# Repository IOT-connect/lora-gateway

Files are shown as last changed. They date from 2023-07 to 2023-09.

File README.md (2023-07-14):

# Lora gateway with ethernet

## Project for make simple and reliable Lora gateway with AVR atmega2560 and ESR-US1 w5500 ethernet

#### 3d view

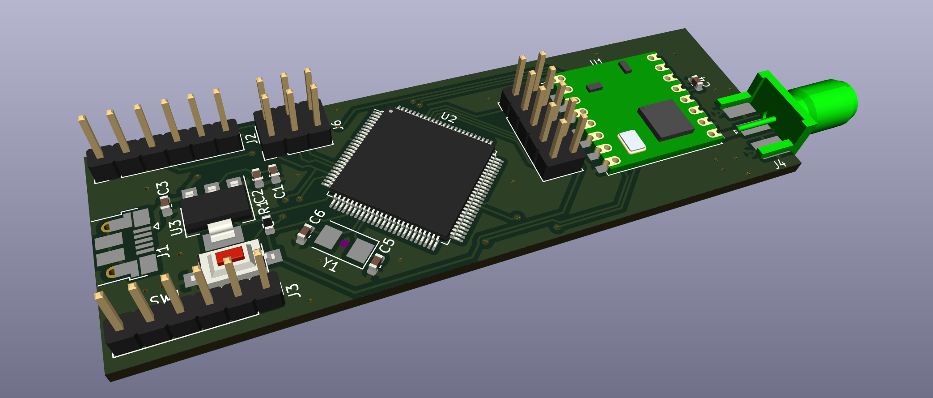
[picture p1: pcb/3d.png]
3d


#### pcb view

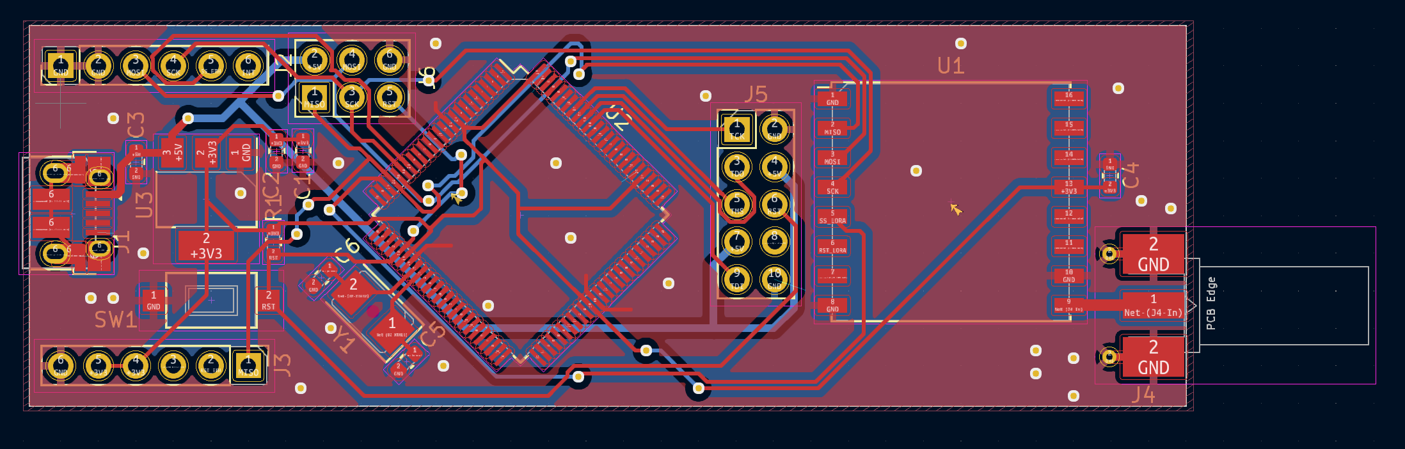
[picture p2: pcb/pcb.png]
pcb


#### schematic view

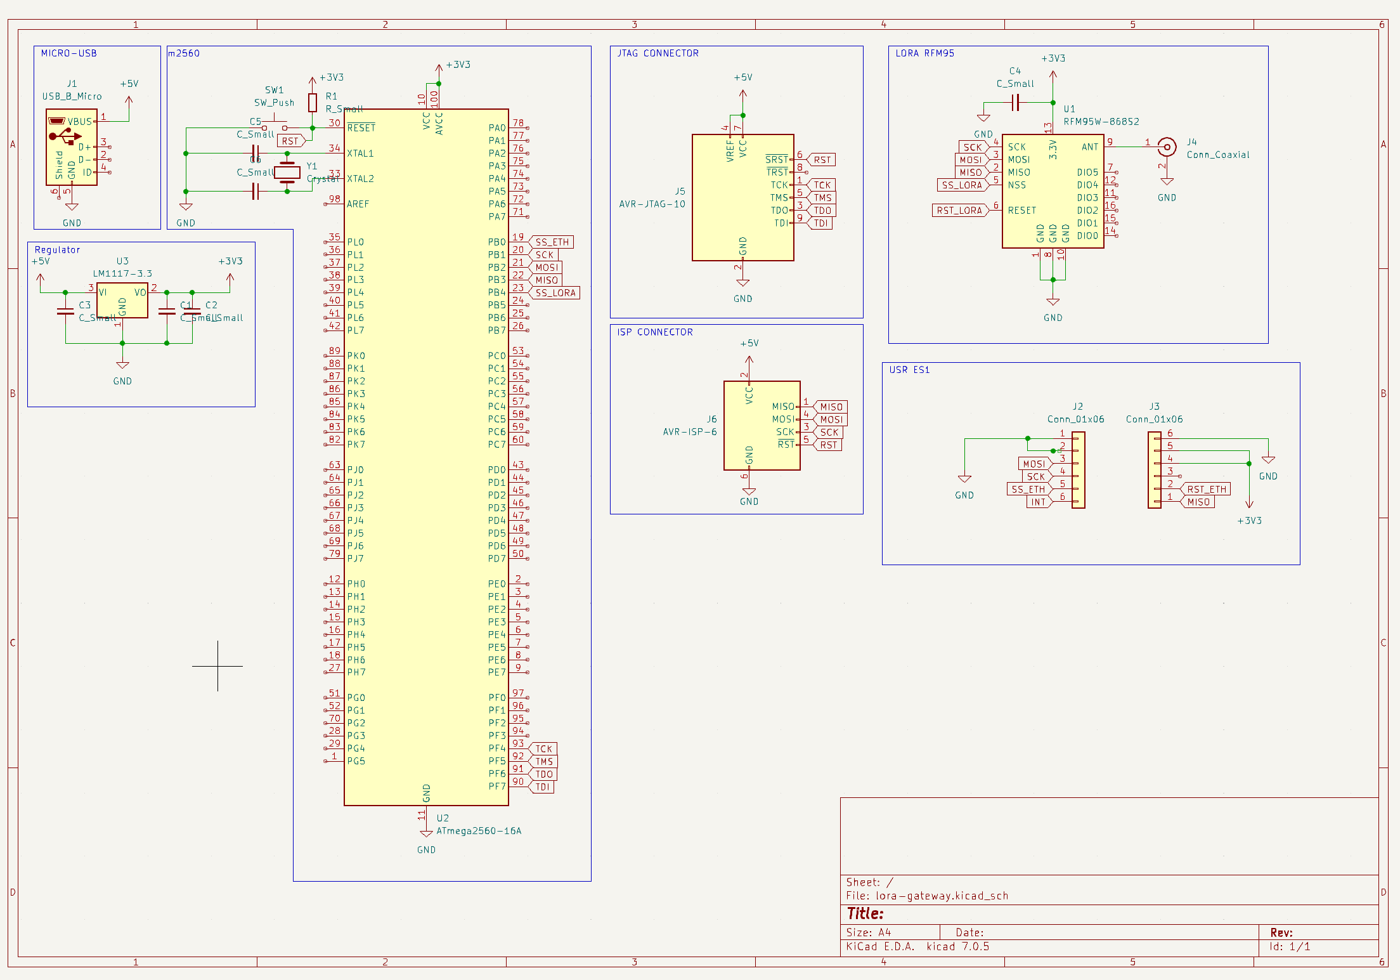
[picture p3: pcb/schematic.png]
schematic


### TODO

- [ ] Add RTC
- [ ] Add temperature sensor

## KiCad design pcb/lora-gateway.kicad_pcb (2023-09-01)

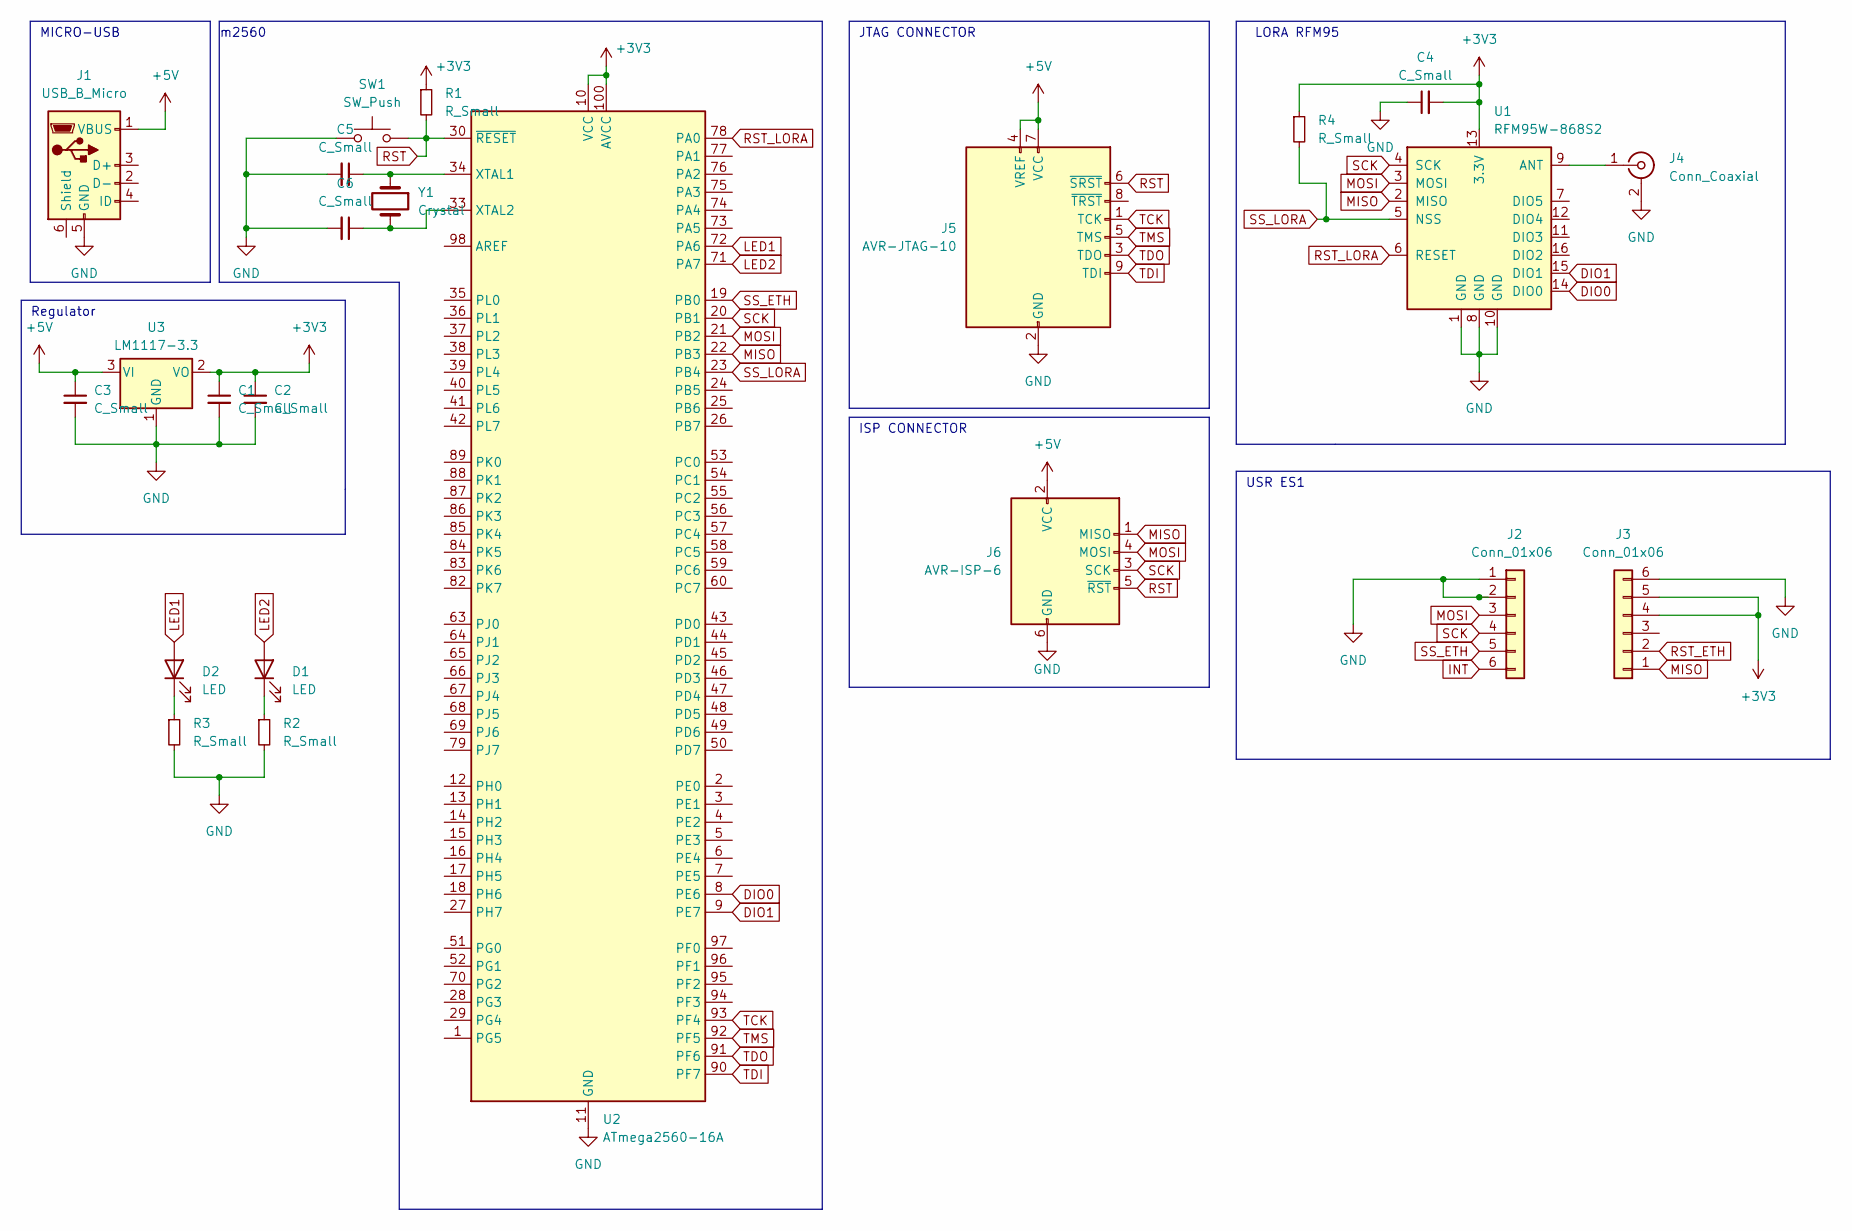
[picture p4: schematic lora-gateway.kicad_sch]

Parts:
C1, C2, C3, C4, C5, C6: C_Small; C_0603_1608Metric
D1, D2: LED; LED_0603_1608Metric
J1: USB_B_Micro; USB_Micro-B_Amphenol_10103594-0001LF_Horizontal
J2, J3: Conn_01x06; PinHeader_1x06_P2.54mm_Vertical
J4: Conn_Coaxial; SMA_Molex_73251-2120_EdgeMount_Horizontal
J5: AVR-JTAG-10; PinHeader_2x05_P2.54mm_Vertical
J6: AVR-ISP-6; PinHeader_2x03_P2.54mm_Vertical
R1, R2, R3, R4: R_Small; R_0603_1608Metric
SW1: SW_Push; SW_SPST_CK_RS282G05A3
U1: RFM95W-868S2; HOPERF_RFM9XW_SMD
U2: ATmega2560-16A; TQFP-100_14x14mm_P0.5mm
U3: LM1117-3.3; SOT-223-3_TabPin2
Y1: Crystal; Crystal_SMD_5032-2Pin_5.0x3.2mm

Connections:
+3V3: C1.1, C2.1, C4.2, J3.4, J3.5, R1.1, R4.1, U1.13 (3.3V), U2.10 (VCC), U2.31 (VCC), U2.61 (VCC), U2.80 (VCC), U2.100 (AVCC), U3.2 (VO)
+5V: C3.1, J1.1 (VBUS), J5.4 (VREF), J5.7 (VCC), J6.2 (VCC), U3.3 (VI)
DIO0: U1.14 (DIO0), U2.8 (PE6)
DIO1: U1.15 (DIO1), U2.9 (PE7)
GND: C1.2, C2.2, C3.2, C4.1, C5.2, C6.2, J1.5 (GND), J2.1, J2.2, J3.6, J4.2 (Ext), J5.2 (GND), J5.10 (GND), J6.6 (GND), R2.2, R3.2, SW1.1, U1.1 (GND), U1.8 (GND), U1.10 (GND), U2.11 (GND), U2.32 (GND), U2.62 (GND), U2.81 (GND), U2.99 (GND), U3.1 (GND)
INT: J2.6
LED1: D2.2 (A), U2.72 (PA6)
LED2: D1.2 (A), U2.71 (PA7)
MISO: J3.1, J6.1 (MISO), U1.2 (MISO), U2.22 (PB3)
MOSI: J2.3, J6.4 (MOSI), U1.3 (MOSI), U2.21 (PB2)
unnamed: D1.1 (K), R2.1
unnamed: D2.1 (K), R3.1
unnamed: J4.1 (In), U1.9 (ANT)
unnamed: C5.1, U2.34 (XTAL1), Y1.1
unnamed: C6.1, U2.33 (XTAL2), Y1.2
RST: J5.6 (~SRST), J6.5 (~RST), R1.2, SW1.2, U2.30 (~RESET)
RST_ETH: J3.2
RST_LORA: U1.6 (RESET), U2.78 (PA0)
SCK: J2.4, J6.3 (SCK), U1.4 (SCK), U2.20 (PB1)
SS_ETH: J2.5, U2.19 (PB0)
SS_LORA: R4.2, U1.5 (NSS), U2.23 (PB4)
TCK: J5.1 (TCK), U2.93 (PF4)
TDI: J5.9 (TDI), U2.90 (PF7)
TDO: J5.3 (TDO), U2.91 (PF6)
TMS: J5.5 (TMS), U2.92 (PF5)

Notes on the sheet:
USR ES1
Regulator
ISP CONNECTOR
MICRO-USB
m2560
LORA RFM95
JTAG CONNECTOR

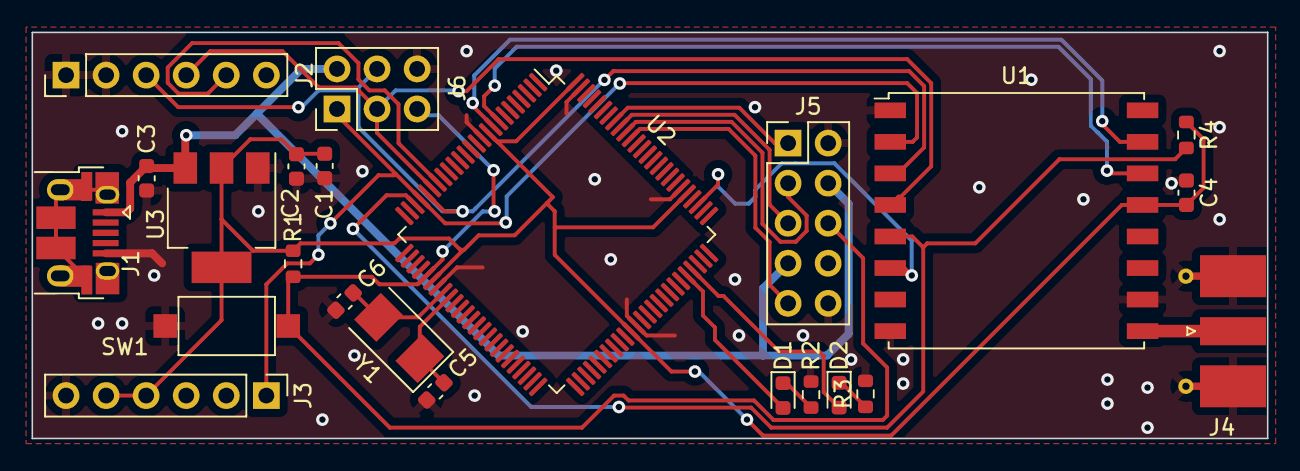
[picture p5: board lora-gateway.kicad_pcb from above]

Board: 2 copper layers, 78.3 x 25.8 mm, 23 parts (0 on the bottom side), 23 nets.

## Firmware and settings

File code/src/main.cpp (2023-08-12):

#include <Arduino.h>
#include <SPI.h>
#include <Ethernet3.h>
#include <EthernetUdp3.h>
#include <RadioLib.h>

#include <SoftwareSerial.h>

#define LED1 PIN_PA6
#define LED2 PIN_PA7

SoftwareSerial Serial5(A5,A6);

byte mac[] = {
  0xDE, 0xAD, 0xBE, 0xEF, 0xFE, 0xED
};

unsigned int localPort = 1883;    //10002;  // local port to listen on

char packetBuffer[UDP_TX_PACKET_MAX_SIZE]; //buffer to hold incoming packet,
char ReplyBuffer[] = "acknowledged";       // a string to send back

EthernetUDP Udp;
RFM95 radio = new Module(19, 0, 0, 0);

void setup() {
  pinMode(LED1, OUTPUT);
  Serial5.begin(9600);
  delay(2000);
  Ethernet.setCsPin(PIN_PB0);
  Ethernet.begin(mac);

  Udp.begin(2000);

  Serial.print(F("[SX1278] Initializing ... "));
  int state = radio.begin(868.0);
  if (state == RADIOLIB_ERR_NONE) {
    Serial5.println(F("success!"));
  } else {
    Serial5.print(F("failed, code "));
    Serial5.println(state);
    while (true);
  }



  Serial5.println(Ethernet.localIP());
}

void loop() {
  int packetSize = Udp.parsePacket();
  if (packetSize)
  {
    Serial5.print("Received packet of size ");
    Serial5.println(packetSize);
    Serial5.print("From ");
    IPAddress remote = Udp.remoteIP();
    for (int i = 0; i < 4; i++)
    {
      Serial5.print(remote[i], DEC);
      if (i < 3)
      {
        Serial5.print(".");
      }
    }
    Serial5.print(", port ");
    Serial5.println(Udp.remotePort());

    Udp.read(packetBuffer, UDP_TX_PACKET_MAX_SIZE);
    Serial5.println("Contents:");
    Serial5.println(packetBuffer);

    // send a reply, to the IP address and port that sent us the packet we received
    Udp.beginPacket(Udp.remoteIP(), Udp.remotePort());
    Udp.write(ReplyBuffer);
    Udp.endPacket();
  }
  delay(10);
}

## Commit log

2023-07-10 add m2560 + rfm95
    [lora-gateway.kicad_sch]
2023-07-11 add board + usr es1 connector
    [lora-gateway.kicad_pcb, lora-gateway.kicad_sch]
2023-07-11 add regulator
    [lora-gateway.kicad_pcb, lora-gateway.kicad_sch]
2023-07-14 add isp + jtag connector
    [lora-gateway.kicad_sch]
2023-07-14 pcb wiring
    [lora-gateway.kicad_pcb, lora-gateway.kicad_sch]
2023-07-14 up schematic
    [lora-gateway.kicad_sch]
2023-07-14 up pcb
    [lora-gateway.kicad_pcb]
2023-07-26 add leds
    [lora-gateway.kicad_pcb, lora-gateway.kicad_sch]
2023-07-29 add rfm95 wiring
    [lora-gateway.kicad_pcb, lora-gateway.kicad_sch]
2023-07-30 add gnd to micro usb
    [lora-gateway.kicad_pcb, lora-gateway.kicad_sch]
2023-08-12 add led pin
2023-08-12 add usb gnd
    [lora-gateway.kicad_pcb]
2023-09-01 change DIO0 & DIO1 to interrupt pin
    [lora-gateway.kicad_pcb, lora-gateway.kicad_sch]
